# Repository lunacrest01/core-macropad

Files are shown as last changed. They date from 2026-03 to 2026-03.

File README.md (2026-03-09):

Core

Core-W is a wireless 3×3 macropad with one rotary encoder and RGB underglow support. It runs custom firmware and software on an ESP32-S3 module with BLE HID and BLE GATT support.

⸻⸻⸻⸻⸻⸻⸻⸻⸻⸻⸻⸻⸻⸻⸻⸻⸻⸻⸻⸻

*FEATURES*

•	9 mechanical switches

•	1 rotary encoder

•	RGB underglow lighting

•   BLE HID/GATT

⸻⸻⸻⸻⸻⸻⸻⸻⸻⸻⸻⸻⸻⸻⸻⸻⸻⸻⸻⸻

*CAD*




⸻⸻⸻⸻⸻⸻⸻⸻⸻⸻⸻⸻⸻⸻⸻⸻⸻⸻⸻⸻

PCB

The PCB manages the switch and encoder matrix, controls the RGB features, and handles battery charging.


wireless pcb


⸻⸻⸻⸻⸻⸻⸻⸻⸻⸻⸻⸻⸻⸻⸻⸻⸻⸻⸻⸻

*HANDWIRING*

The columns of the switches need to be hand-wired, while the encoder and the switch rows will be connected individually on the PCB.



Wiring Guide

Encoder
A → GPIO10
B → GPIO12

Matrix (Keypad)
Rows:

Row 1 → GPIO1

Row 2 → GPIO2

Row 3 → GPIO3

Columns:

Col 1 → GPIO7

Col 2 → GPIO8

Col 3 → GPIO9

RGB
DIN (D1) → GPIO4

⸻⸻⸻⸻⸻⸻⸻⸻⸻⸻⸻⸻⸻⸻⸻⸻⸻⸻⸻⸻

*OVERVIEW*

Core-W is a wireless 3×3 macropad featuring a rotary encoder and RGB underglow. Powered by the ESP32-S3 microcontroller, it is designed to support BLE HID and BLE GATT for wireless communication, running on custom-developed firmware and software

When transitioning the device to wireless functionality, two main firmware options were considered ZMK and RMK

ZMK requires reserving a key for the studio interface and currently lacks proper support for encoders and reactive RGB lighting

RMK presents similar limitations, particularly in encoder functionality and advanced RGB features

Due to these constraints, I decided to develop my own firmware and software to fully leverage the hardware capabilities of the Core-W

⸻⸻⸻⸻⸻⸻⸻⸻⸻⸻⸻⸻⸻⸻⸻⸻⸻⸻⸻⸻

Idea / Approach
    •	Send key inputs to the host using BLE HID
	•	Receive data for live key remapping
	•	Communication can be done using BLE GATT services or USB
	
⸻⸻⸻⸻⸻⸻⸻⸻⸻⸻⸻⸻⸻⸻⸻⸻⸻⸻⸻⸻

*HOW TO USE*

Enter Flash Mode: Connect your ESP32-S3 to your computer. Press and hold the BOOT button, then press and release the RESET button. Finally, release the BOOT button. The device is now ready to receive new firmware.

Select Board in Arduino IDE: Open the Arduino IDE. Go to Tools > Board > Board Manager, search for and install the ESP32 platform if you haven't already. Then, navigate to Tools > Board > ESP32 Arduino and select the "ESP32S3 Dev Module" .

Customize Your Layout: To modify the key functions, open the keymap.cpp file in the Arduino IDE. Edit the keymap array to assign the desired keystrokes or actions to each key and encoder. Upload the sketch to your device.

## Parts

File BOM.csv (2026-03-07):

Component Category | item | cost | LINK | quatity
case | top | $0.92/ ₹84.56 | https://a3dxyz.com/instant3dp/ | 1
 | base | $1.31/₹120 | https://a3dxyz.com/instant3dp/ | 1
 | encoder cap | $0.38/₹35 | https://a3dxyz.com/instant3dp/ | 1
 | keycap | $1.63/₹150 | https://moddest.in/#/shop/blank-xda-keycap-singles | 8
electronics | pcb | $9.80/₹900 | https://robu.in/product/online-pcb-manufacturing-service/ | 5
 | esp32-s3 | $5.50/₹500 | https://makerbazar.in/products/esp32-c3-supermini-iot-development-board?variant=48753170481392 | 1
 | switches | $4.89/₹449 | https://www.thecosmicbyte.com/product/cherry-mx-mechancial-5-pin-switches-compatible-with-hot-swappable-keyboards-pack-of-10/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 | 10
 | diode | $0.38 /₹35 | https://makerbazar.in/products/sma-schottky-diode-smd-do-214ac?variant=48365556924656 | 20
 | battery | $1.63/₹150 | https://makerbazar.in/products/generic-103450-3-7-v-2000mah-lipo-battery-single-cell-lithium-polymer-battery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 | 1
 | Capacitor | $0.42/₹39 | https://makerbazar.in/products/0805-smd-smt-mlcc-capacitor | 10
 | resistor | $0.13/₹12 | https://makerbazar.in/products/0603-smd-surface-mount-chip-resistors | 20
 | encoder | $0.53/₹49 | https://makerbazar.in/products/360-degrees-rotary-encoder-module-brick-sensor-switch-development-ky-040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 | 1
 | RGB | $1.04/₹96 | https://makerbazar.in/products/ws2812b-5050-rgb-led-lamp-panel-module?variant=48251035189488 | 4
 | WIRES | $0.87/₹80 | https://makerbazar.in/products/flexible-silicon-wire?variant=47855779545328 | 19AWG,26AWG
screw
 | M2-10mm(allen) | $0.33/₹30 | https://onlyscrews.in/products/m2-x-10mm-hex-allen-socket-head-high-tensile12-9-black-oxide-screw-dia-2mm-length-10mm | 4
 | m2-5mm philips | $0.22/₹20 | https://onlyscrews.in/products/m2-x-4mm-phillips-round-head-laptop-screw-dia-2mm-length-5mm | 4
 | brass insert 3mm | $0.11/₹10 | https://onlyscrews.in/products/m2-x-3mm-brass-threaded-inserts | 4
TOTAL
 | TOTAL | $30/₹2750

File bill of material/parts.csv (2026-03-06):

Component Category | item | cost | note | LINK | quatity
case | top | $0.92/ ₹84.56 |  | https://a3dxyz.com/instant3dp/ | 1
 | base | $1.31/₹120 |  | https://a3dxyz.com/instant3dp/ | 1
 | encoder cap | $0.38/₹35 |  | https://a3dxyz.com/instant3dp/ | 1
 | keycap | $1.63/₹150 |  |  | 8
electronics | pcb | $9.80/₹900 |  | https://robu.in/product/online-pcb-manufacturing-service/ | 5
 | esp32-s3 | $5.50/₹500 |  | https://hubtronics.in/esp32-s3-supermini-board | 1
 | switches | $4.89/₹449 |  | https://www.thecosmicbyte.com/product/cherry-mx-mechancial-5-pin-switches-compatible-with-hot-swappable-keyboards-pack-of-10/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 | 10
 | diode/capacitor/resistor/rgb | $1.63/₹150 |  | https://quartzcomponents.com/ | diode-9,resitor -,capacitor-4,rgb-4
 | battery | $1.63/₹150 |  | https://quartzcomponents.com/products/3-7v-800mah-li-po-rechargeable-battery?_pos=11&_sid=4138e78e9&_ss=r | 1
screw
 | M2-10mm(allen) | $0.33/₹30 | case mounting | https://onlyscrews.in/products/m2-x-10mm-hex-allen-socket-head-high-tensile12-9-black-oxide-screw-dia-2mm-length-10mm | 4
 | m2-5mm philips | $0.22/₹20 | pcb mounting | https://onlyscrews.in/products/m2-x-4mm-phillips-round-head-laptop-screw-dia-2mm-length-5mm | 4
 | brass insert 3mm | $0.11/₹10 | pcb mounting | https://onlyscrews.in/products/m2-x-3mm-brass-threaded-inserts | 4
Miscellaneous
 | wires/connector/other | $1.65
total |  | $30

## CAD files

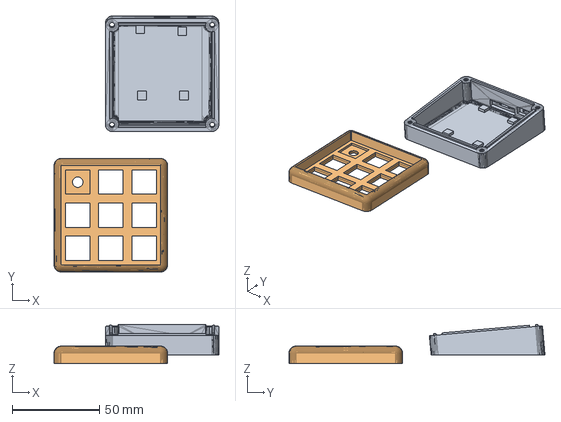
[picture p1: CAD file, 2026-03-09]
CAD/CORE-W.FCStd
94.6 x 146.9 x 22.4 mm
bottom001 (Solid)001
product0 (Solid)001

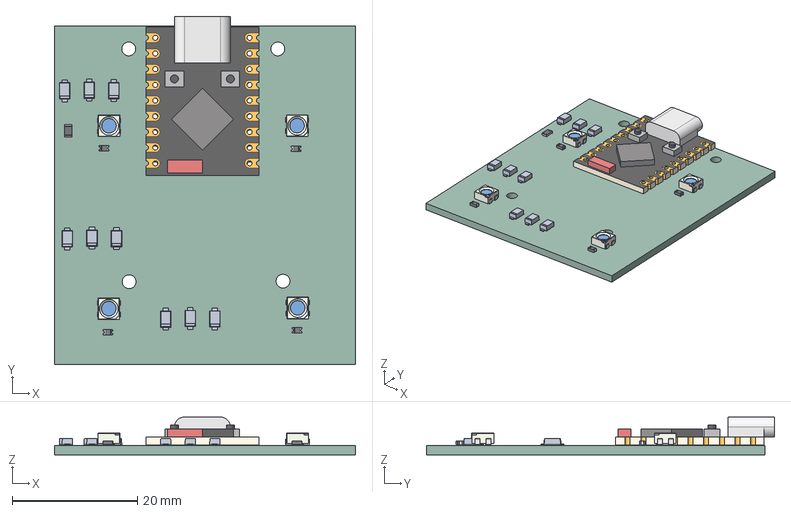
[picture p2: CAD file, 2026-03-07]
PCB/core-w.step
48.0 x 55.6 x 6.04 mm
core-w 1.1.1 x 9
D_0603_1608Metric x 4
LED_WS2812B-Mini_PLCC4_3.5x3.5mm x 4
ESP32S3 Super Mini
R_0805_2012Metric
core-w_PCB

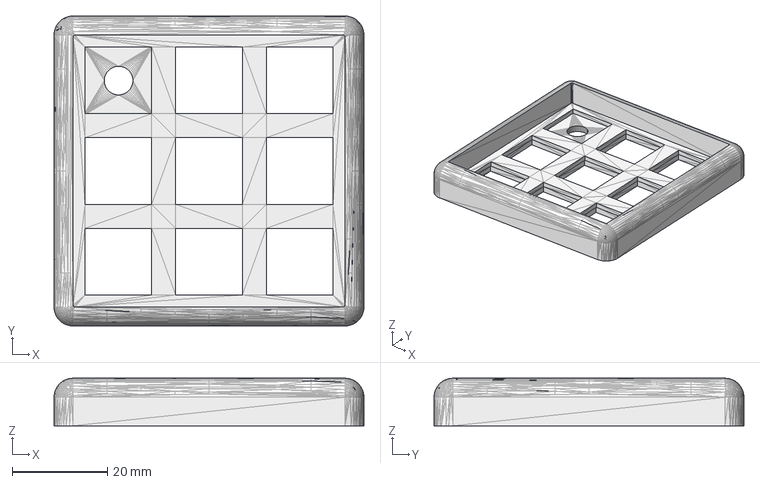
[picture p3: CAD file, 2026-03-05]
production/case/top.step
65.2 x 65.2 x 10.0 mm

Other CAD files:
production/PCB/wireless/core-w.stl

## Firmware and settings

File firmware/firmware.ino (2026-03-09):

#include <Arduino.h>
#include <FastLED.h>

#include "BleKeyboard.h"
#include "config.h"
#include "keymap.h"
#include "debounce.h"
#include "battery.h"

BleKeyboard bleKeyboard(BLE_DEVICE_NAME, BLE_MANUFACTURER, 100);
Battery     battery(BAT_ADC_PIN, BAT_DIVIDER_RATIO, BAT_FULL_MV, BAT_EMPTY_MV);
CRGB        leds[RGB_LED_COUNT];
Debounce    keyDb[ROW_COUNT * COL_COUNT];  

uint8_t  currentLayer = 0;

volatile int32_t encDelta  = 0;   
volatile uint8_t encState  = 0;   

static const int8_t ENC_TABLE[16] = {
     0, -1,  1,  0,
     1,  0,  0, -1,
    -1,  0,  0,  1,
     0,  1, -1,  0
};

void IRAM_ATTR encoderISR() {
    uint8_t a = (uint8_t)digitalRead(ENC_A_PIN);
    uint8_t b = (uint8_t)digitalRead(ENC_B_PIN);
    encState  = ((encState << 2) | (a << 1) | b) & 0x0F;
    encDelta += ENC_TABLE[encState];
}


static const CRGB LAYER_COLOURS[NUM_LAYERS] = {
    CRGB(0, 80, 220),   
    CRGB(200, 20, 20),  
};

void rgbSetLayer() {
    fill_solid(leds, RGB_LED_COUNT, LAYER_COLOURS[currentLayer]);
    leds[8] = CRGB::Gold;   
    FastLED.show();
}

void rgbFlashKey(uint8_t idx) {
    CRGB saved = leds[idx];
    leds[idx]  = CRGB::White;
    FastLED.show();
    delay(KEY_FLASH_MS);
    leds[idx] = saved;
    FastLED.show();
}

void rgbLowBatWarning() {
    for (uint8_t i = 0; i < 3; i++) {
        fill_solid(leds, RGB_LED_COUNT, CRGB::Red);
        FastLED.show();
        delay(150);
        fill_solid(leds, RGB_LED_COUNT, CRGB::Black);
        FastLED.show();
        delay(100);
    }
    rgbSetLayer();
}

void sendKey(const KeyDef &k) {
    if (!bleKeyboard.isConnected()) return;

    switch (k.type) {
        case KTYPE_REGULAR:
            if (k.modifier) bleKeyboard.press(k.modifier);
            if (k.code)     bleKeyboard.press((uint8_t)k.code);
            delay(BLE_KEY_MS);
            bleKeyboard.releaseAll();
            break;

        case KTYPE_MEDIA: {
            MediaKeyReport mr = { (uint8_t)(k.code & 0xFF),
                                  (uint8_t)((k.code >> 8) & 0xFF) };
            bleKeyboard.write(mr);
            break;
        }

        default:
            break;   
    }
}

void scanMatrix() {
    for (uint8_t r = 0; r < ROW_COUNT; r++) {
        digitalWrite(ROW_PINS[r], LOW);
        delayMicroseconds(5);  

        for (uint8_t c = 0; c < COL_COUNT; c++) {
            uint8_t idx    = r * COL_COUNT + c;
            bool    rawLow = (digitalRead(COL_PINS[c]) == LOW);

            if (keyDb[idx].update(rawLow) && keyDb[idx].justPressed()) {
                const KeyDef &k = KEYMAP[currentLayer][idx];

                Serial.printf("[KEY] idx=%u layer=%u type=%u mod=0x%02X code=%u\n",
                              idx, currentLayer, k.type, k.modifier, k.code);

                if (k.type == KTYPE_LAYER) {
                    currentLayer = (uint8_t)k.code;
                    Serial.printf("[LAYER] -> %u\n", currentLayer);
                    rgbSetLayer();
                } else if (k.type != KTYPE_NONE) {
                    sendKey(k);
                    rgbFlashKey(idx);
                }
            }
        }

        
        digitalWrite(ROW_PINS[r], HIGH);
    }
}

void handleEncoder() {
    const int8_t ENC_TICKS_PER_DETENT = 4;

    int32_t delta = 0;
    noInterrupts();
    delta    = encDelta;
    encDelta = 0;
    interrupts();

    int32_t detents = delta / ENC_TICKS_PER_DETENT;

    for (int32_t i = 0; i < detents; i++) {
        Serial.println("[ENC] CW");
        sendKey(ENC_MAP[currentLayer][0]);  
    }
    for (int32_t i = 0; i > detents; i--) {
        Serial.println("[ENC] CCW");
        sendKey(ENC_MAP[currentLayer][1]);   
    }
}

void handleBattery() {
    if (!battery.needsReport(BAT_REPORT_MS)) return;

    battery.printStats();
    uint8_t pct = battery.getPercent();

    if (bleKeyboard.isConnected()) {
        bleKeyboard.setBatteryLevel(pct);
    }

    if (pct <= BAT_LOW_WARN_PCT) {
        rgbLowBatWarning();
    }
}

void rgbIdleAnimate() {
    static uint8_t hue  = 0;
    static uint32_t lastMs = 0;
    if ((millis() - lastMs) < 30) return;
    lastMs = millis();
    fill_rainbow(leds, RGB_LED_COUNT, hue, 255 / RGB_LED_COUNT);
    FastLED.show();
    hue++;
}

void setup() {
    Serial.begin(115200);
    delay(200);
    Serial.println("=== MacroPad S3 boot ===");

    // Matrix rows
    for (uint8_t r = 0; r < ROW_COUNT; r++) {
        pinMode(ROW_PINS[r], OUTPUT);
        digitalWrite(ROW_PINS[r], HIGH);  
    }
    for (uint8_t c = 0; c < COL_COUNT; c++) {
        pinMode(COL_PINS[c], INPUT_PULLUP);
    }

    pinMode(ENC_A_PIN, INPUT_PULLUP);
    pinMode(ENC_B_PIN, INPUT_PULLUP);
    encState = ((uint8_t)digitalRead(ENC_A_PIN) << 1) | (uint8_t)digitalRead(ENC_B_PIN);
    attachInterrupt(digitalPinToInterrupt(ENC_A_PIN), encoderISR, CHANGE);
    attachInterrupt(digitalPinToInterrupt(ENC_B_PIN), encoderISR, CHANGE);

    for (uint8_t i = 0; i < ROW_COUNT * COL_COUNT; i++) {
        keyDb[i].setDebounceMs(DEBOUNCE_MS);
    }

  
    FastLED.addLeds<WS2812B, RGB_DATA_PIN, GRB>(leds, RGB_LED_COUNT);
    FastLED.setBrightness(RGB_BRIGHTNESS);
    fill_solid(leds, RGB_LED_COUNT, CRGB::Black);
    FastLED.show();

    battery.begin();
    battery.printStats();

    uint8_t initPct = battery.getPercent();
    bleKeyboard.begin();
    bleKeyboard.setBatteryLevel(initPct);
    Serial.printf("[BLE] Advertising as \"%s\"  (bat=%u%%)\n",
                  BLE_DEVICE_NAME, initPct);
}

void loop() {
    if (bleKeyboard.isConnected()) {
        static bool wasConnected = false;
        if (!wasConnected) {
            wasConnected = true;
            Serial.println("[BLE] Connected!");
            rgbSetLayer();
        }

        scanMatrix();
        handleEncoder();
        handleBattery();

    } else {
        static bool wasConnected = true;
        if (wasConnected) {
            wasConnected = false;
            Serial.println("[BLE] Disconnected - advertising...");
        }
        rgbIdleAnimate();   
        delay(10);
    }
}

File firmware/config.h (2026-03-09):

#pragma once

#define BLE_DEVICE_NAME  "Core-W"
#define BLE_MANUFACTURER "Lunacrest"

#define ROW_COUNT  3
#define COL_COUNT  3
static const uint8_t ROW_PINS[ROW_COUNT] = { 1, 2, 3 };   
static const uint8_t COL_PINS[COL_COUNT] = { 7, 8, 9 };   

#define ENC_A_PIN   10  
#define ENC_B_PIN   12  
#define ENC_SW_ROW  2
#define ENC_SW_COL  2    

#define RGB_DATA_PIN    4    
#define RGB_LED_COUNT   9
#define RGB_BRIGHTNESS  70   

#define BAT_ADC_PIN          6      
#define BAT_DIVIDER_RATIO    2.0f
#define BAT_FULL_MV          4200   
#define BAT_EMPTY_MV         3000   
#define BAT_LOW_WARN_PCT     15     
#define BAT_REPORT_MS        30000UL  

#define DEBOUNCE_MS  20  

#define NUM_LAYERS   2

#define KEY_FLASH_MS  35   
#define BLE_KEY_MS    12   

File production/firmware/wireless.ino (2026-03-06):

#include <Arduino.h>
#include "config.h"
#include "keymap.h"
#include "matrix.h"
#include "encoder.h"
#include "rgb.h"
#include "battery.h"
#include "blekeyboard.h"

// Global objects
MatrixScanner matrix;
Encoder encoder(ENC_A, ENC_B);
RGBController rgb(RGB_DATA_PIN);
BatteryMonitor battery(BATTERY_PIN, CHARGING_PIN);
BLEKeyboard bleKeyboard;

// Variables
uint8_t currentLayer = 0;
uint32_t lastMatrixScan = 0;
uint32_t lastKeySend = 0;
const uint16_t MATRIX_SCAN_INTERVAL = 5;   
const uint16_t KEY_REPORT_INTERVAL = 10;   

void setup() {
    Serial.begin(115200);
    matrix.begin();
    encoder.begin();
    rgb.begin();
    battery.begin();
    bleKeyboard.begin();

    rgb.setLayerColor(currentLayer);
}

void loop() {
    uint32_t now = millis();


    if (now - lastMatrixScan >= MATRIX_SCAN_INTERVAL) {
        matrix.scan();
        lastMatrixScan = now;
    }


    int8_t encDir = encoder.getDirection();
    if (encDir != 0) {
        uint8_t keycode = (encDir > 0) ? encoder_actions[currentLayer].clockwise : encoder_actions[currentLayer].counterClockwise;
        uint8_t report[1] = { keycode };
        bleKeyboard.sendKeys(0, report, 1);
        delay(KEY_REPORT_INTERVAL);
        bleKeyboard.sendKeys(0, NULL, 0);
    }

    uint8_t pressedKeys[6];
    uint8_t pressedCount = 0;
    uint8_t modifiers = 0; 

    for (int r = 0; r < ROWS; r++) {
        for (int c = 0; c < COLS; c++) {
            if (matrix.getKeyPress(r, c)) {
                uint8_t keycode = keymaps[currentLayer][r][c];
                if (keycode != 0) {
                    pressedKeys[pressedCount++] = keycode;
                    if (pressedCount >= 6) break;
                }
            }
        }
    }

    if (pressedCount > 0 && (now - lastKeySend >= KEY_REPORT_INTERVAL)) {
        bleKeyboard.sendKeys(modifiers, pressedKeys, pressedCount);
        lastKeySend = now;
    } else if (pressedCount == 0 && (now - lastKeySend >= KEY_REPORT_INTERVAL)) {
        bleKeyboard.sendKeys(modifiers, NULL, 0);
        lastKeySend = now;
    }.
    static bool layerSwitchPending = false;
    if (matrix.getKeyPress(0, 2)) { 
        if (!layerSwitchPending) {
            layerSwitchPending = true;
            currentLayer = (currentLayer + 1) % LAYERS;
            rgb.setLayerColor(currentLayer);
        }
    } else {
        layerSwitchPending = false;
    }

    battery.update();
    uint8_t battPercent = battery.getPercentage();
    bleKeyboard.setBatteryLevel(battPercent);
    rgb.setCharging(battery.isCharging());

    bleKeyboard.update();

    delay(1);
}

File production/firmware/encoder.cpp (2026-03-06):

#include "encoder.h"
#include <Arduino.h>

Encoder::Encoder(uint8_t pinA, uint8_t pinB) : aPin(pinA), bPin(pinB), direction(0) {}

void Encoder::begin() {
    pinMode(aPin, INPUT_PULLUP);
    pinMode(bPin, INPUT_PULLUP);
    attachInterruptArg(digitalPinToInterrupt(aPin), isrHandler, this, CHANGE);
    attachInterruptArg(digitalPinToInterrupt(bPin), isrHandler, this, CHANGE);
}

void IRAM_ATTR Encoder::isrHandler(void* arg) {
    Encoder* enc = static_cast<Encoder*>(arg);
    enc->handleInterrupt();
}

void Encoder::handleInterrupt() {
    static uint8_t lastState = 0;
    uint8_t a = digitalRead(aPin);
    uint8_t b = digitalRead(bPin);
    uint8_t state = (a << 1) | b;
    // Gray code transition table
    if (state != lastState) {
        if ((lastState == 0 && state == 1) || (lastState == 1 && state == 3) ||
            (lastState == 3 && state == 2) || (lastState == 2 && state == 0)) {
            direction++;
        } else if ((lastState == 0 && state == 2) || (lastState == 2 && state == 3) ||
                   (lastState == 3 && state == 1) || (lastState == 1 && state == 0)) {
            direction--;
        }
        lastState = state;
    }
}

int8_t Encoder::getDirection() {
    int8_t val;
    noInterrupts();
    val = direction;
    direction = 0;
    interrupts();
    return val;
}

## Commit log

2026-03-07 Revise readme formatting and add CAD screenshot
    Updated section separators and added CAD image.
2026-03-07 Revise README formatting and add images
    Updated separators and added new images for CAD and PCB sections.
2026-03-07 Update CAD section formatting in readme.md
2026-03-07 Update and rename parts.csv to BOM.csv
    [BOM.csv]
2026-03-07 Clarify photo shows wired version of the macropad
    Added a note indicating the photo shows the wired version.
2026-03-07 Update README with usage instructions for ESP32-S3
    Added usage instructions for flashing and customizing the ESP32-S3.
2026-03-08 Update README with PCB and handwiring information
    Added details about PCB functionality and handwiring requirements.
2026-03-09 Update wiring guide with encoder and matrix details
